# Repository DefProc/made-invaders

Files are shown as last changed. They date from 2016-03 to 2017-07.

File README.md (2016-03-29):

# made-invaders

A repo and issues list for the Made Invaders installation

The original test target display is the [ledframe](https://git.defproc.co.uk/DefProc/ledframe)

larger issues and discussins are in the [issues](https://github.com/DoESLiverpool/made-invaders/issues) but minute-by-minute planning is in the [trello board](https://trello.com/b/ncKjq608/made-invaders)

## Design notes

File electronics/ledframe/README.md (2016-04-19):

Known Issues
============

rev 1
-----

 * The 5V and ground on CON1 are reversed
   * **The D1, U1 and U3 WILL be damaged if the board is powered up**
   * Cutting the ground connections and the 5V line around the pads *must* be done
   before soldering. Then reversed connections will need to be added manually.
 * both SW1 and SW2 are rotated 90 degress from the correct connections.
   * Cutting diagonally opposed legs from the button before assembly will allow
   normal operation.
 * The ISCP slave select (SS) line is shared between IC1 and U2.
   * The ATmega *must* be programmed with a bootloader *before* soldering.
   * To program via ISCP, cut the RADIO_SS line between IC1 and U2.
 * The level converter (Q2, R3, R4) is too slow for the transmission speed required
 for the WS2812b LEDs.
   * Do not place Q1, R3 or R4. Make a bridge connection between pins 2–3 of Q2.

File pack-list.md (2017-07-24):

You will need:

 - [ ] Gazebo
 - [ ] 15 targets
 - [ ] Timer
 - [ ] Scoreboard
 - [ ] Blank boxes ×20
 - [ ] 2× 12v DC supply
 - [ ] Target power supply
 - [ ] Extra DC power cables
 - [ ] long kettle lead for the targets power
 - [ ] 2× Long 2way extensions
 - [ ] Play stand (and bucket o'darts)
 - [ ] the bowl of RFID tags
 - [ ] 15× Carpet tiles for flooring
 - [ ] Registration station Pi
 - [ ] RPi power supply
 - [ ] Keyboard
 - [ ] Monitor (hdmi)
 - [ ] Monitor power lead
 - [ ] HDMI cable
 - [ ] 4× Sidestrike nerf guns (the green ones)
 - [ ] 4× Jolt nerf guns (the small ones)
 - [ ] Battery nerf gun
 - [ ] 2× 12 shot clip
 - [ ] 1× 18 shot clip
 - [ ] Pull up banner
 - [ ] Hazard tape
 - [ ] Zip ties
 - [ ] 7× Safety glasses
 - [ ] M6x12 Bolts
 - [ ] M6x15 button cap bolts
 - [ ] M6 nuts

## If available

 - [ ] T-shirts
 - [ ] Stickers
 - [ ] Badges

## Maybe

 - [ ] Masking tape
 - [ ] Network cable
 - [ ] Network switch
 - [ ] Extensions
 - [ ] Power cable (for switch)
 - [ ] WiFi bridge laptop
 - [ ] Spare mouse

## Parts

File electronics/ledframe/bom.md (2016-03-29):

The BOM is on octopart at: [octopart.com/bom-lookup/logzmHi8](https://octopart.com/bom-lookup/logzmHi8).

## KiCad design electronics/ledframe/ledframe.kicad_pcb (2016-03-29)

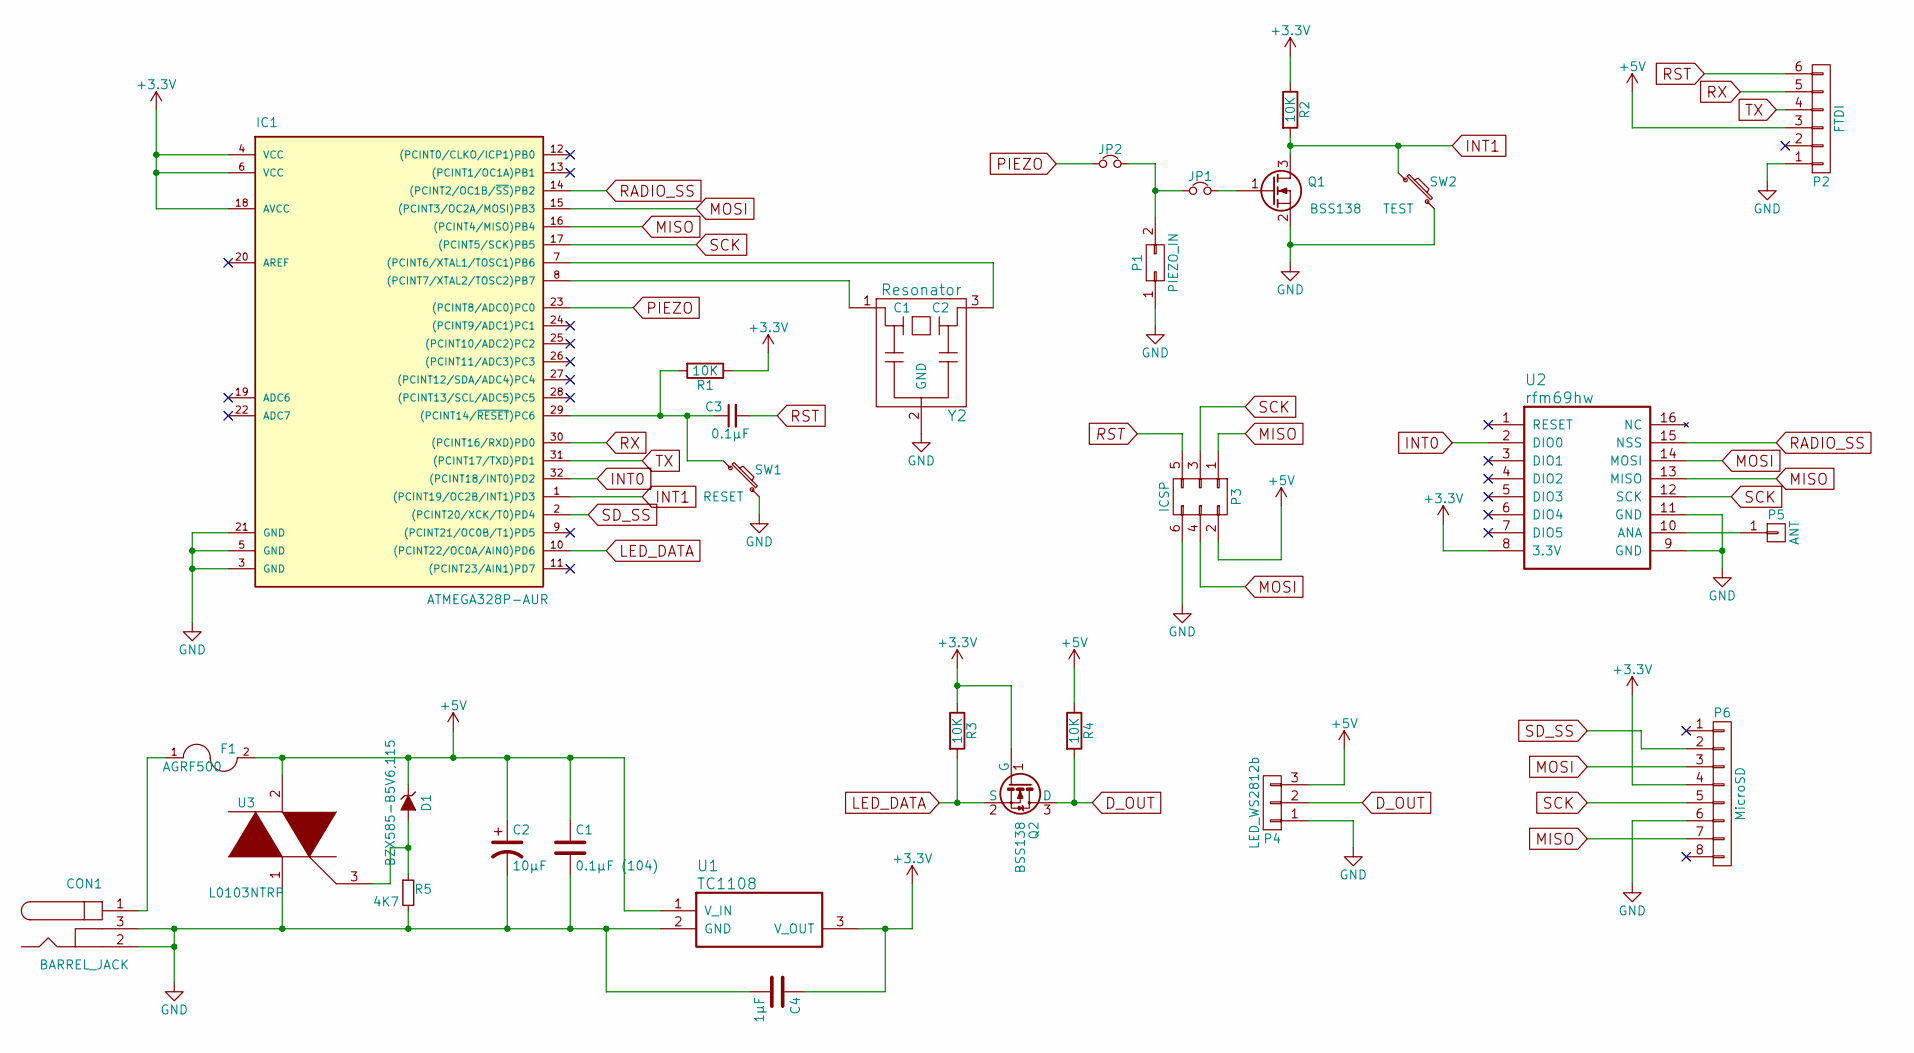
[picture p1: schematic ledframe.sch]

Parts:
C1: 0.1µF (104); C_0603
C2: 10µF; c_elec_3x5.3
C3: 0.1µF; C_0603
C4: 1µF; C_0805
CON1: BARREL_JACK
D1: BZX585-B5V6,115; SOD-523
F1: AGRF500; Resistor_Horizontal_RM7mm
IC1: ATMEGA328P-AUR; TQFP-32_7x7mm_Pitch0.8mm
JP1, JP2: Jumper_NC_Small; NC_SMD_JPR
P1: PIEZO_IN; Pin_Header_Straight_2x01
P2: FTDI; Pin_Header_Straight_1x06
P3: ICSP; Pin_Header_Straight_2x03
P4: LED_WS2812b; Pin_Header_Straight_1x03
P5: ANT; Socket_Strip_Straight_1x01
P6: MicroSD; MicroSD_Molex_47309
Q1, Q2: BSS138; SOT-23
R1, R2, R3, R4: 10K; R_0603
R5: 4K7; R_0603
SW1: RESET; KSEx00G_SW
SW2: TEST; KSEx00G_SW
U1: TC1108; SOT-223
U2: rfm69hw; DIP-16_W7.62mm
U3: L0103NTRP; SOT-223
Y2: Resonator; Resonator_3.2x1.3

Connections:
+3V3: C4.1, IC1.4 (VCC), IC1.6 (VCC), IC1.18 (AVCC), P6.4, Q2.1 (G), R1.1, R2.1, R3.1, U1.3 (V_OUT), U2.8 (3.3V)
+5V: C1.1, C2.1, D1.1 (K), F1.2, P2.3, P3.2, P4.3, R4.1, U1.1 (V_IN), U3.2
D_OUT: P4.2, Q2.3 (D), R4.2
GND: C1.2, C2.2, C4.2, CON1.2, CON1.3, IC1.3 (GND), IC1.5 (GND), IC1.21 (GND), P1.1, P2.1, P3.6, P4.1, P6.6, Q1.2 (S), R5.2, SW1.2, SW2.2, U1.2 (GND), U2.9 (GND), U2.11 (GND), U3.1, Y2.2 (GND)
INT0: IC1.32 ((PCINT18/INT0)PD2), U2.2 (DIO0)
INT1: IC1.1 ((PCINT19/OC2B/INT1)PD3), Q1.3 (D), R2.2, SW2.1
LED_DATA: IC1.10 ((PCINT22/OC0A/AIN0)PD6), Q2.2 (S), R3.2
MISO: IC1.16 ((PCINT4/MISO)PB4), P3.1, P6.7, U2.13 (MISO)
MOSI: IC1.15 ((PCINT3/OC2A/MOSI)PB3), P3.4, P6.3, U2.14 (MOSI)
unnamed: C3.1, IC1.29 ((PCINT14/~RESET~)PC6), R1.2, SW1.1
unnamed: CON1.1, F1.1
unnamed: D1.2 (A), R5.1, U3.3
unnamed: IC1.7 ((PCINT6/XTAL1/TOSC1)PB6), Y2.3 (C2)
unnamed: IC1.8 ((PCINT7/XTAL2/TOSC2)PB7), Y2.1 (C1)
unnamed: JP1.1, JP2.2, P1.2
unnamed: JP1.2, Q1.1 (G)
unnamed: P5.1, U2.10 (ANA)
PIEZO: IC1.23 ((PCINT8/ADC0)PC0), JP2.1
RADIO_SS: IC1.14 ((PCINT2/OC1B/~SS~)PB2), U2.15 (NSS)
RST: C3.2, P2.6, P3.5
RX: IC1.30 ((PCINT16/RXD)PD0), P2.5
SCK: IC1.17 ((PCINT5/SCK)PB5), P3.3, P6.5, U2.12 (SCK)
SD_SS: IC1.2 ((PCINT20/XCK/T0)PD4), P6.2
TX: IC1.31 ((PCINT17/TXD)PD1), P2.4

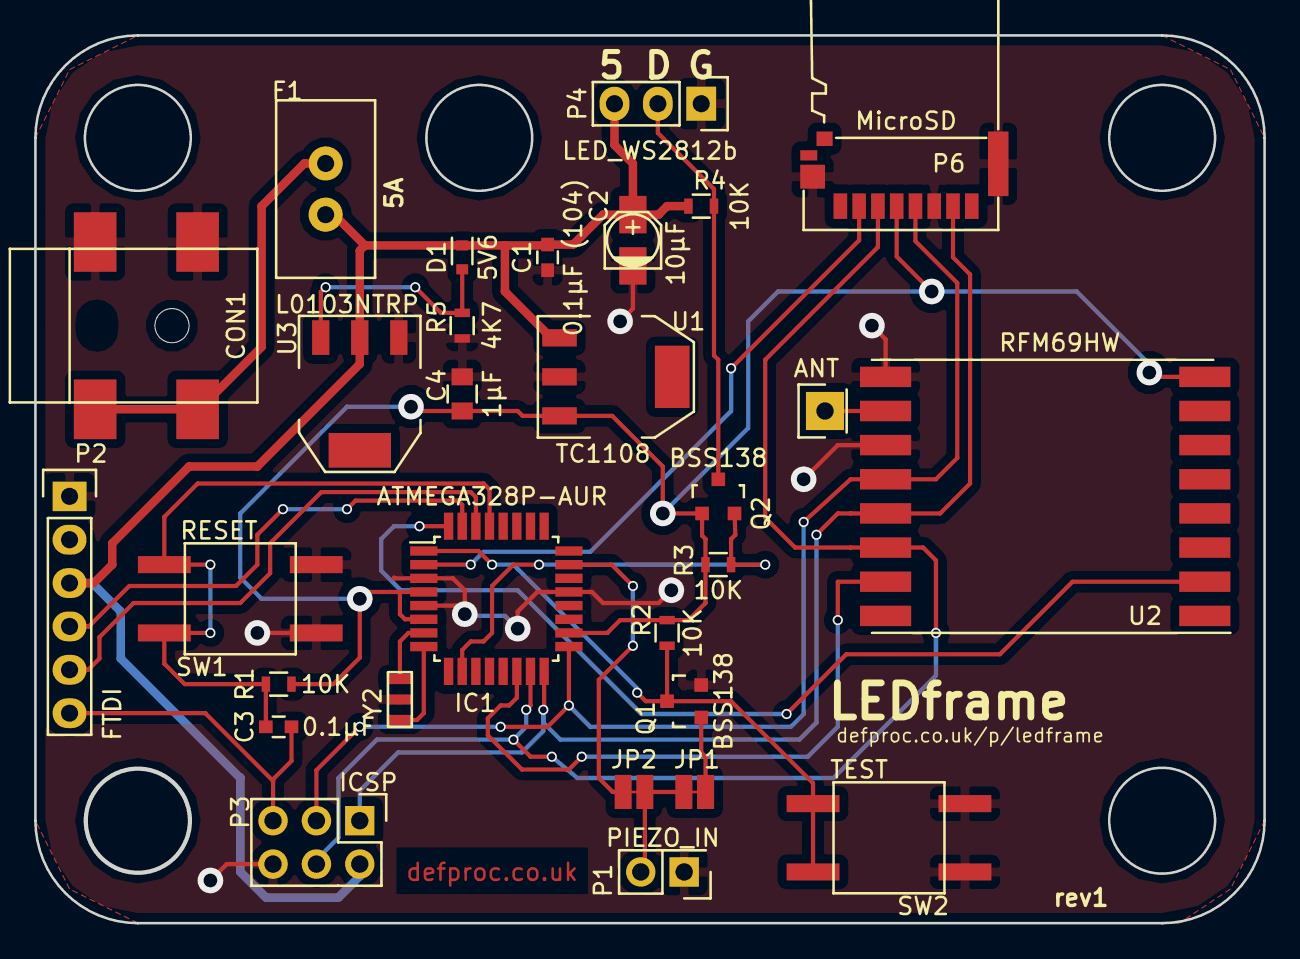
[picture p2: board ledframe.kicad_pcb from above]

Board: 2 copper layers, 72.0 x 52.0 mm, 29 parts (0 on the bottom side), 24 nets.

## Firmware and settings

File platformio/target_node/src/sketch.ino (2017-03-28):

#include "FastLED.h"
#include <SdFat.h>
#include <TimerOne.h>
#include <RFM69.h>
#include <SPI.h>
#include <Entropy.h>
#include <EEPROM.h>
#include "constants.h"
#include "secrets.h"
SdFat sd;
SdFile myFile;

// The unique identifier of this node
// targets are numbered 1-16,
uint8_t node_id;
RFM69 radio;

Payload myPacket;

// How many numbered images on the SD card?
uint8_t num_images;

#define BUTTON 3 // pin for the test button
#define BUTTON_TEST_DELAY 2000 // how long to press the button for test mode

#define BUFFPIXEL 20
#define NUM_LEDS 90
#define ARRAY_WIDTH 9
#define ARRAY_HEIGHT 9
#define DATA_PIN 6
// set the inital (default) frame hold time
#define FRAME_DELAY 250
// Define the array of leds
CRGB leds[NUM_LEDS];
// Error messages stored in flashread16(myFile).
#define error(msg) sd.errorHalt(F(msg))
// timer frequency for the ADC
const unsigned char PS_16 = (1 << ADPS2);
const unsigned char PS_128 = (1 << ADPS2) | (1 << ADPS1) | (1 << ADPS0);

// possible image states
enum image_state_t {
  STATIC,
  VERTICAL,
  HORIZONTAL
};

// System Setup
volatile boolean
  changeImage = true; // should we change the image to the next one?
boolean
  game_over = false,
  is_ready_to_play = false,
  show_help = false,
  test_images = false, // should we check the number of images on the SD (slow)
  singleGraphic = false, // single BMP file
  setupActive = false; // set brightness, playback mode, etc.
int
  currentButtonState = HIGH,
  lastButtonState = HIGH,
  offsetX = 0, // for translating images x pixels
  offsetY = 0; // for translating images y pixels
uint8_t
  analogThreshold = 70, // above what value should we take a reading as activated
  currentFrame = 0, // whick frame are we displaying
  numFrames = 1, // how many frames in the image animation?
  currentImage = -1; // which image are we looking at
uint16_t
  //currentScore = 0,
  imageWidth = 0,
  imageHeight = 0;
uint32_t
  gameStartTime = 0UL,
  frameDelay = FRAME_DELAY, // the time to hold each animation frame
  lastImageUpdate = 0UL, // when did we last change the displayed image
  impactRepeat = 100UL, // debounce timeout for the sensor
  idleAnimationSpacing = 1000;
volatile uint32_t
  lastButton = 0UL, // when did we last press the button
  lastImpact = 0UL; // when did we last see a hit
game_states_t play_state = RUNNING; // start the game running, allows demo from power on
image_state_t image_state = STATIC;
Payload theData; // incoming message buffer

int showImage(char* filename, uint32_t frame_delay = frameDelay, uint8_t first_frame = currentFrame, uint16_t num_frames = 0, uint16_t repeat_number = 1);

void setup() {
  Entropy.initialize();
  randomSeed(Entropy.random());

  Serial.begin(BAUD);
  Serial.println("starting target_node v1.1.0");

  // get the node id from EEPROM
  EEPROM.get(NODE_LOC, node_id);
  // check it's sensible, or reset to default
  if (node_id < NODE_MIN || node_id > NODE_MAX) {
    node_id = NODE_MIN;
    EEPROM.put(NODE_LOC, node_id);
  }
  Serial.print(F("I am target: "));
  Serial.println(node_id);

  // wait a small amount of time to prevent all the
  // targets from starting at once
  delay(100 * node_id);

  // set up the ADC sampling speed
  ADCSRA &= ~PS_128;  // remove bits set by Arduino library
  ADCSRA |= PS_16;    // set the prescaler to 16 (1MHz)

  // initialize the LED string
  FastLED.addLeds<WS2812,DATA_PIN,GRB>(leds,NUM_LEDS);
  FastLED.setBrightness(84);
  fill_solid(leds, NUM_LEDS, CRGB::Black);
  FastLED.show();

  // start the SD card
  if (!sd.begin(4, 6)) {
    // display an error pattern on SD fail
    showError(1);
    sd.initErrorHalt();
  } else {
    Serial.println(F("SD began"));
    //sd.ls(LS_R);
  }

  // get the number of images from EEPROM
  EEPROM.get(IMAGE_LOC, num_images);
  // check it's sensible, or reset to default
  if (num_images < IMAGE_DEFAULT || num_images > IMAGE_MAX) {
    num_images = IMAGE_DEFAULT;
    EEPROM.put(IMAGE_LOC, num_images);
  }
  Serial.print(F("Number of Images: "));
  Serial.println(num_images);

  // initialize the radio
  radio.initialize(FREQUENCY,node_id,NETWORKID);
  #ifdef IS_RFM69HW
  radio.setHighPower(); //uncomment only for RFM69HW!
  #endif
  radio.encrypt(ENCRYPTKEY);

  // show the colour wipe, so we know the display's working
  colour_wipe();

  // draw the invader logo
  clearStripBuffer();
  FastLED.show();
  delay(100);
  showImage("invader.bmp");
  delay(2000);
  clearStripBuffer();
  FastLED.show();

  // if we start RUNNING, start listening for hits
  if (play_state == RUNNING) { startScoring(); }
}

void showError(uint8_t error_code) {
  fill_solid(leds, NUM_LEDS, CRGB::Black);
  fill_solid(leds, error_code, CRGB::Red);
  FastLED.show();
}

void startScoring() {
  // Start the fast interrupt for the analog read
  pinMode(A0, INPUT);
  // TODO: include the analog input for more reliable scoring
  Timer1.initialize(10000); // run at 100Hz
  Timer1.attachInterrupt(checkImpact);

  // and start watching INT1 for too
  pinMode(3, INPUT);
  attachInterrupt(INT1, piezoInt, FALLING);

  gameStartTime = millis() - 1500UL;
  //currentScore = 0;
}

void stopScoring() {
  Timer1.detachInterrupt();
  detachInterrupt(INT1);
}

void fadeall() { for(int i = 0; i < NUM_LEDS; i++) { leds[i].nscale8(250); } }

void loop() {
  if (play_state == RFID_SCANNED) {
    // set the first image
    if (is_ready_to_play == false) {
      // pick a random image
      currentImage = random(0,num_images);
      char filename_buffer[13];
      sprintf(filename_buffer, "%04d.bmp", currentImage+1);
      if (sd.exists(filename_buffer)) {
        Serial.print(F("displaying "));
        Serial.println(filename_buffer);
        // show the first frame if it's an animation
        showImage(filename_buffer, 0, 0, 1);
        is_ready_to_play = true;
      } else {
        currentImage++;
        currentImage = currentImage % num_images;
      }
    } else if (image_state != STATIC && millis() - lastImageUpdate >= frameDelay) {
      // we should update the current image if it's an animation at it's time to
      char filename_buffer[13];
      sprintf(filename_buffer, "%04d.bmp", currentImage+1);
      // we've already checked that this exists
      showImage(filename_buffer, 0, currentFrame, 1);
    }
  } else if (play_state == RUNNING) {
    if (changeImage == true) {
      // change the image (ASAP)
      // TODO: this is where a better destroy animation should go
      destroy();
      // Then report the hit via the RFM69
      myPacket.message_id = HIT;
      myPacket.impact_num++;
      myPacket.timestamp = millis() - gameStartTime;
      if (radio.sendWithRetry(MAIN_CTRL, (const void*)(&myPacket), sizeof(myPacket), 5)) {
        Serial.println(F("sent impact message"));
      } else {
        Serial.println(F("no radio message sent"));
        showError(3);
      }
      //Then show the next character
      // TODO: we should at least check that we don't get the same number again
      currentImage = random(0,num_images);
      char filename_buffer[13];
      sprintf(filename_buffer, "%04d.bmp", currentImage+1);
      if (sd.exists(filename_buffer)) {
        Serial.print(F("displaying "));
        Serial.println(filename_buffer);
        showImage(filename_buffer, 0, 0, 1);
        changeImage = false;
      }
    } else if (image_state != STATIC && millis() - lastImageUpdate >= frameDelay) {
      // we should update the current image if it's an animation at it's time to
      char filename_buffer[13];
      sprintf(filename_buffer, "%04d.bmp", currentImage+1);
      // we've already checked that this exists
      showImage(filename_buffer, 0, currentFrame, 1);
    }
  } else if (play_state == END_GAME) {
    if (game_over == true) {
      // show a red screen for the finish
      fill_solid(leds, NUM_LEDS, CRGB::Red);
      for (uint8_t i; i<10; i++) {
        FastLED.show();
        delay(100);
        for (int j; j<NUM_LEDS; j++) {
          leds[j].fadeToBlackBy(64);
        }
      }
      fill_solid(leds, NUM_LEDS, CRGB::Black);
      FastLED.show();
      game_over = false;
    }
  } else if (play_state == IDLE) {
    bool go_to_test_mode = false;

    // if there's any serial available, read it:
    while (Serial.available() > 0) {
      char character = Serial.read();
      if (character == 't' || character == 'T') {
        test_images = false;
        show_help = true;
        go_to_test_mode = true;
      } else if (character == 's' || character == 'S') {
        play_state = RUNNING;
        startScoring();
      }
    }

    // check if we should be changing to TEST mode
    currentButtonState = digitalRead(BUTTON);
    if (digitalRead(BUTTON) == LOW) {
      // button is pressed
      if (currentButtonState != lastButtonState) {
        // it's just been pressed
        lastButton = millis();
        lastButtonState = currentButtonState;
        Serial.print(F("button pressed, counting"));
      } else {
        if (millis() - lastButton >= BUTTON_TEST_DELAY) {
          // enter test mode
          Serial.println(F("held long enough"));
          test_images = true;
          show_help = false;
          go_to_test_mode = true;
        }
      }
    } else {
      // button is released
      lastButtonState = currentButtonState;
    }

    if (go_to_test_mode == true) {
        Serial.println(F("Testing mode (reset to exit)"));
        Serial.println(F("n<number> to set node_id (1-16)"));
        Serial.println(F("i to recount the number of images"));
        show_help = true;
        play_state = TEST;
    }

    // just show a scrolling
    if (millis() - lastImageUpdate >= idleAnimationSpacing) {
      // TODO: it sometimes freezes on the animation
      //showImage("title.bmp", 30);
      // lets try a pulse instead
      uint8_t fade_colour = random(5);
      switch (random(5)) {
        case 1:
          fill_solid(leds, NUM_LEDS, CRGB::Magenta);
          break;
        case 2:
          fill_solid(leds, NUM_LEDS, CRGB::Red);
          break;
        case 3:
          fill_solid(leds, NUM_LEDS, CRGB::Yellow);
          break;
        case 4:
          fill_solid(leds, NUM_LEDS, CRGB::Green);
          break;
        default:
          fill_solid(leds, NUM_LEDS, CRGB::White);
          break;
      }
      FastLED.show();
      for (int i=0; i<10; i++) {
        leds[i].fadeToBlackBy(64);
        FastLED.show();
        delay(10);
      }
      fill_solid(leds, NUM_LEDS, CRGB::Black);
      FastLED.show();
      lastImageUpdate = millis();
      idleAnimationSpacing = random(2500, 30000);
    } else {
      fill_solid(leds, NUM_LEDS, CRGB::Black);
      FastLED.show();
    }
  } else if (play_state == TEST) {
    while (Serial.available() > 0) {
      char character = Serial.read();

      if (character == 'h' || character == 'H') {
        // show the menu
        show_help = true;
      }

      if (character == 'n' || character == 'N') {
        // set node id
        uint8_t new_node_id = Serial.parseInt();
        EEPROM.update(NODE_LOC, new_node_id);
        Serial.print(F("Node ID set to: "));
        Serial.println(new_node_id);
        Serial.println(F("reset to use"));
      }

      if (character == 'i' || character == 'I') {
        // count the images on the SD card
        test_images = true;
      }

      if (character == 'x' || character == 'q' || character == 'X' || character == 'Q') {
        play_state = IDLE;
        Serial.println(F("go to IDLE mode"));
      }
    }

    if (test_images == true) {
      // check the number of images on the SD card
      Serial.println(F("checking the number of images on the card"));
      Serial.println(F("we may be some time"));
      fill_solid(leds, NUM_LEDS, CRGB::Green);
      FastLED.show();
      delay(100);
      fill_solid(leds, NUM_LEDS, CRGB::Black);
      FastLED.show();
      uint8_t num_images = 0;
      for (int i = 0; i<=IMAGE_MAX; i++) {
        char filename_buffer[13];
        sprintf(filename_buffer, "%04d.bmp", i+1);
        //myFile.close();
        Serial.print(filename_buffer);
        if (sd.exists(filename_buffer)) {
          showImage(filename_buffer, 0, 0, 1);
          delay(250);
          for (int j=0; j<i; j++) {
            leds[j] = CRGB::Yellow;
          }
          FastLED.show();
          Serial.println(F(" exists"));
          num_images++;
          delay(100);
        } else {
          Serial.println(F(" not found"));
          break;
        }
      }
      Serial.print(num_images);
      Serial.println(F(" images found"));
      test_images = false;
      //write this value to the EEPROM for next time
      EEPROM.update(IMAGE_LOC, num_images);
      delay(500);
      fill_solid(leds, NUM_LEDS, CRGB::Black);
      FastLED.show();
    }

    if (show_help == true) {
      // show the possible options
      Serial.println(F("Testing mode (reset to exit)"));
      Serial.println(F("n<number> to set node_id (1-16)"));
      Serial.println(F("i to recount the number of images"));
      Serial.println(F("x|q to quit to IDLE mode"));
      show_help = false;
    }
  } // end of state machine

  // let's check any incoming messages
  checkIncoming();
}

void colour_wipe() {
  static uint8_t hue = 0;
  Serial.print("x");
  // First slide the led in one direction
  for(int i = 0; i < NUM_LEDS; i++) {
    // Set the i'th led to red
    leds[i] = CHSV(hue++, 255, 255);
    // Show the leds
    FastLED.show();
    //now that we've shown the leds, reset the i'th led to black
    // leds[i] = CRGB::Black;
    fadeall();
    // Wait a little bit before we loop around and do it again
    delay(10);
  }
  Serial.print("x");

  // Now go in the other direction.
  for(int i = (NUM_LEDS)-1; i >= 0; i--) {
    // Set the i'th led to red
    leds[i] = CHSV(hue++, 255, 255);
    // Show the leds
    FastLED.show();
    // now that we've shown the leds, reset the i'th led to black
    // leds[i] = CRGB::Black;
    fadeall();
    // Wait a little bit before we loop around and do it again
    delay(10);
  }
}

void checkImpact() {
  if (analogRead(A0) >= analogThreshold && millis() - lastImpact >= impactRepeat) {
    changeImage = true;
    lastImpact = millis();
    //currentScore++;
  }
}

void piezoInt() {
  if (millis() - lastImpact >= impactRepeat) {
    changeImage = true;
    lastImpact = millis();
    //currentScore++;
    //Serial.println(F("interrupt"));
  }
}

void destroy() {
  fill_solid(leds, NUM_LEDS, CRGB::Black);
  FastLED.show();
  delay(50);
  //fill_solid(leds, NUM_LEDS, CRGB::Red);
  for (uint8_t i=0; i<NUM_LEDS; i++) {
    if (random(10) < 7) { leds[i] = CRGB::Red; }
  }
  FastLED.show();
  delay(50);
  fill_solid(leds, NUM_LEDS, CRGB::Black);
  FastLED.show();
  delay(50);
  //fill_solid(leds, NUM_LEDS, CRGB::Orange);
  for (uint8_t i=0; i<NUM_LEDS; i++) {
    if (random(10) < 4) { leds[i] = CRGB::White; }
  }
  FastLED.show();
  delay(50);
  fill_solid(leds, NUM_LEDS, CRGB::Black);
  FastLED.show();
  delay(50);
  //fill_solid(leds, NUM_LEDS, CRGB::Yellow);
  for (uint8_t i=0; i<NUM_LEDS; i++) {
    if (random(10) < 1) { leds[i] = CRGB::Yellow; }
  }
  FastLED.show();
  delay(50);
  fill_solid(leds, NUM_LEDS, CRGB::Black);
  FastLED.show();
  delay(100);
}

// This function opens a Windows Bitmap (BMP) file and
// displays it at the given coordinates.  It's sped up
// by reading many pixels worth of data at a time
// (rather than pixel by pixel).  Increasing the buffer
// size takes more of the Arduino's precious RAM but
// makes loading a little faster.  20 pixels seems a
// good balance.

void bmpDraw(char *filename, uint8_t x, uint8_t y) {

  int  bmpWidth, bmpHeight;   // W+H in pixels
  uint8_t  bmpDepth;              // Bit depth (currently must be 24)
  uint32_t bmpImageoffset;        // Start of image data in file
  uint32_t  rowSize;               // Not always = bmpWidth; may have padding
  uint8_t  sdbuffer[3*BUFFPIXEL]; // pixel buffer (R+G+B per pixel)
  uint8_t  buffidx = sizeof(sdbuffer); // Current position in sdbuffer
  boolean  goodBmp = false;       // Set to true on valid header parse
  boolean  flip    = true;        // BMP is stored bottom-to-top
  int  w, h, row, col;
  uint8_t  r, g, b;
  uint32_t pos = 0;
  const uint8_t  gridWidth = ARRAY_WIDTH;
  const uint8_t  gridHeight = ARRAY_HEIGHT;

  //if((x >= gridWidth) || (y >= gridHeight)) {
    //Serial.print(F("Abort."));
    //return;
  //}

  Serial.println();

  if (!myFile.isOpen())
  {
    //Serial.print(F("Loading image '"));
    //Serial.print(filename);
    //Serial.println('\'');
    // Open requested file on SD card
    myFile.close();
    if (!myFile.open(filename, O_READ)) {
      Serial.print(F("File open failed "));
      Serial.println(filename);
      //sdErrorMessage();
      //try reinitialise:
      showError(1);
      sd.begin(4,6);
      return;
    }
  }
  else myFile.rewind();

  // Parse BMP header
  uint16_t bmp_sig = read16(myFile);
  //if(read16(myFile) == 0x4D42) { // BMP signature
  if(bmp_sig == 0x4D42) { // BMP signature
    Serial.print(F("File size: ")); Serial.println(read32(myFile));
    (void)read32(myFile); // Read & ignore creator bytes
    bmpImageoffset = read32(myFile); // Start of image data
    Serial.print(F("Image Offset: ")); Serial.println(bmpImageoffset, DEC);
    // Read DIB header
    Serial.print(F("Header size: ")); Serial.println(read32(myFile));
    bmpWidth  = read32(myFile);
    bmpHeight = read32(myFile);
    if(read16(myFile) == 1) { // # planes -- must be '1'
      bmpDepth = read16(myFile); // bits per pixel
      //Serial.print(F("Bit Depth: ")); Serial.println(bmpDepth);
      if((bmpDepth == 24) && (read32(myFile) == 0)) { // 0 = uncompressed

        goodBmp = true; // Supported BMP format -- proceed!
        //Serial.print(F("Image size: "));
        //Serial.print(bmpWidth);
        //Serial.print('x');
        //Serial.println(bmpHeight);

        //Serial.print(F("Image offset: "));
        //Serial.print(offsetX);
        //Serial.print(F(", "));
        //Serial.println(offsetY);

        // image smaller than 16x16?
        if ((bmpWidth < ARRAY_WIDTH && bmpWidth > -ARRAY_WIDTH) || (bmpHeight < ARRAY_HEIGHT && bmpHeight > -ARRAY_HEIGHT))
        {
          clearStripBuffer();
        }

        // BMP rows are padded (if needed) to 4-byte boundary
        rowSize = (bmpWidth * 3 + 3) & ~3;;
        //Serial.print(F("Row size: "));
        //Serial.println(rowSize);


        // If bmpHeight is negative, image is in top-down order.
        // This is not canon but has been observed in the wild.
        if(bmpHeight < 0) {
          bmpHeight = -bmpHeight;
          flip      = false;
        }

        // Crop area to be loaded
        w = bmpWidth;
        h = bmpHeight;
        if((x+w-1) >= gridWidth)  w = gridWidth - x;
        if((y+h-1) >= gridHeight) h = gridHeight - y;

        for (row=0; row<h; row++) { // For each scanline...

          // Seek to start of scan line.  It might seem labor-
          // intensive to be doing this on every line, but this
          // method covers a lot of gritty details like cropping
          // and scanline padding.  Also, the seek only takes
          // place if the file position actually needs to change
          // (avoids a lot of cluster math in SD library).

          if(flip) // Bitmap is stored bottom-to-top order (normal BMP)
            pos = (bmpImageoffset + (offsetX * -3) + (bmpHeight - 1 - (row + offsetY)) * rowSize);
          else     // Bitmap is stored top-to-bottom
            pos = bmpImageoffset + row * rowSize;
          if(myFile.curPosition() != pos) { // Need seek?
            myFile.seekSet(pos);
            buffidx = sizeof(sdbuffer); // Force buffer reload
          }

          for (col=0; col<w; col++) { // For each pixel...
            // Time to read more pixel data?
            if (buffidx >= sizeof(sdbuffer)) { // Indeed
              myFile.read(sdbuffer, sizeof(sdbuffer));
              buffidx = 0; // Set index to beginning
            }

            // push to LED buffer
            b = sdbuffer[buffidx++];
            g = sdbuffer[buffidx++];
            r = sdbuffer[buffidx++];

            // offsetY is beyond bmpHeight
            if (row >= bmpHeight - offsetY)
            {
              // black pixel
              leds[getIndex(col, row)] = CRGB::Black;
              //led[getIndex(col, row)] strip.Color(0, 0, 0));
            }
            // offsetY is negative
            else if (row < offsetY * -1)
            {
              // black pixel
              leds[getIndex(col, row)] = CRGB::Black;
              //strip.setPixelColor(getIndex(col, row), strip.Color(0, 0, 0));
            }
            // offserX is beyond bmpWidth
            else if (col >= bmpWidth + offsetX)
            {
              // black pixel
              leds[getIndex(col, row)] = CRGB::Black;
              //strip.setPixelColor(getIndex(col, row), strip.Color(0, 0, 0));
            }
            // offsetX is positive
            else if (col < offsetX)
            {
              // black pixel
              leds[getIndex(col, row)] = CRGB::Black;
              //strip.setPixelColor(getIndex(col, row), strip.Color(0, 0, 0));
            }
            // all good
            else {
              leds[getIndex(col+x, row)].setRGB(r, g, b);
              //strip.setPixelColor(getIndex(col+x, row), strip.Color(r, g, b));
            }
            // paint pixel color
          } // end pixel
        } // end scanline
      } // end goodBmp
    }
  }
  FastLED.show();

  if (singleGraphic == false || setupActive == true)
  {
    //Serial.println(F("Closing Image..."));
    myFile.close();
  }
  if(!goodBmp) {
    Serial.print(F("Format unrecognized: "));
    Serial.println(bmp_sig);
    showError(8);
  }
}
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

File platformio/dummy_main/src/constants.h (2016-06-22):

// some basic constants for everybody
#define BAUD 115200 // serial baud rate is then contsant accross all devices
#define RFID_DIGITS 16 // max number of chars to hold an scanned ID
#define NUM_TARGETS 16 // how many targets do we have

// target node EEPROM locations
#define NODE_LOC 1
#define NODE_MIN 1
#define NODE_MAX 16
#define IMAGE_LOC 5
#define IMAGE_DEFAULT 5
#define IMAGE_MAX 200

// some unsigned long values for the various timer lengths
#define RUN_TIMER 30000UL // play time in ms
#define GRACE_TIMER 250UL // this is a bit of a fude so it *looks* like the game ends at zero
#define EARLY_PLAY 1000UL
#define EXTRA_TIMER 30000UL // how much extra time for a zero score
#define IDLE_TIMER 60000UL // wait a minute before going into attract mode
#define COUNT_DOWN 5000UL

// RFM69 constants
#define NETWORKID     101  // The same on all nodes that talk to each other
#define MAIN_CTRL     200  // The Main Controller
#define REG_STN       201  // Registration station interpretter (to RPi)
#define TIMER         202  // Countdown Timer
#define SCOREBD       203  // The Score Board
#define FREQUENCY     RF69_868MHZ
#define IS_RFM69HW

// set the possible messages (in message_id)
enum message_t : uint8_t {
  GAME_START,
  TAKE_PHOTO,
  GAME_END,
  NOTHING_DOING,
  CANCEL_GAME,
  GET_READY,
  HIT,
  DISPLAY_NUM,
  MORE_TIME,
  FALSE_START,
  RUN_COUNTDOWN,
};

typedef struct {
  message_t message_id = GAME_START;
  uint32_t impact_num = 0UL;
  long timestamp = 0L;
  char rfid_num[RFID_DIGITS+1];
  uint32_t game_uid;
  long score = 0L;
} Payload;

enum game_states_t {
  IDLE,
  RFID_SCANNED,
  COUNTDOWN,
  RUNNING,
  EXTRA_TIME,
  END_GAME,
  TEST
};

// to allow builtin LED use on Moteino/Moteino Mega
#ifdef __AVR_ATmega1284P__
  #define LED           15 // Moteino MEGAs have LEDs on D15
  #define FLASH_SS      23 // and FLASH SS on D23
#else
  #define LED           9 // Moteinos have LEDs on D9
  #define FLASH_SS      8 // and FLASH SS on D8
#endif

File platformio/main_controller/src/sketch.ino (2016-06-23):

#include <SD.h>
#include <RFM69.h>
#include <SPI.h>
#include <SPIFlash.h>
#include <avr/wdt.h>
#include <WirelessHEX69.h>
#include <Wire.h>
#include <SL018.h>
#include <RTClib.h>
#include <SOMO_II.h>
#include "constants.h"
#include "secrets.h"

SL018 rfid;
RFM69 radio;
SPIFlash flash(FLASH_SS, 0xEF30); //EF30 for windbond 4mbit flash

// set the appropiate node ID
#define NODEID MAIN_CTRL    // The Gateway runs on node 200

// set up the somo-ii connection
SOMO_II mp3 = SOMO_II(Serial1);

// button and led connections
#define START_BUTTON  13
#define CANCEL_BUTTON 12
#define START_LED     15

// Lets get the global variables some space
Payload theData; // somewhere to store incoming data
Payload myPacket; // and one for oddutgoing
game_states_t game_state = IDLE;
char player_rfid[RFID_DIGITS+1];
long
  remaining_game_time = 0,
  current_score = 0;
unsigned long
  number_of_hits = 0,
  start_time = 0,
  game_uid = 0;
volatile bool
  update_scoreboard = false,
  take_photo = false;

// set the target scores:
long scoremap[] = { 101, 236, 553, 100, 1234, 5120, -100, 999, 1024, 512, 256, 128, 200, 865, 6547, 450 };
unsigned long hit_record[sizeof(scoremap)];

void setup() {
  // idiot pause on startup
  delay(2000);

  Wire.begin();
  Serial.begin(BAUD);
  Serial.println("starting made-invaders main_controller…");

  // initialise the music player
  Serial1.begin(SOMO_BAUD);
  mp3.begin();
  Serial.println(F("MP3 OK"));
  delay (1000);

  mp3.playFile(1, 6); //new start file
  Serial.println(F("Playing START.MP3"));

  // initialize the radio
  radio.initialize(FREQUENCY,NODEID,NETWORKID);
#ifdef IS_RFM69HW
  radio.setHighPower();
#endif
  radio.encrypt(ENCRYPTKEY);

  // set up the button an led pins
  pinMode(START_LED, OUTPUT);
  pinMode(START_BUTTON, INPUT);
  pinMode(CANCEL_BUTTON, INPUT);

  // lets just prep the rfid array with zeros
  for (int i=0; i<RFID_DIGITS; i++) {
    myPacket.rfid_num[i] = '0';
  }

  Blink(START_LED, 1000);
  Serial.println(F("end of setup"));
}

uint16_t ackCount = 0;
void loop() {
  // start the state machine
  if (game_state == IDLE) {

    Serial.println(F("IDLE state"));
    start_time = millis();
    bool nothing_doing = false; // have we sent a "nothing doing" message
    // hold for rfid read
    Serial.println(F("waiting for rfid tag"));
    // we're waiting for an RFID scan
    rfid.seekTag();
    unsigned long play_repeat = 360000;
    unsigned long last_played_at = millis() - play_repeat + IDLE_TIMER;
    while (!rfid.available()) {
      if (nothing_doing == false) {
        if (millis() - start_time >= IDLE_TIMER) {
          Serial.println(F("nothing doing"));
          // broadcast NOTHING_DOING to go to idle mode
          myPacket.game_uid = 0;
          myPacket.impact_num = 0;
          myPacket.score = 0;
          for (int i=0; i<RFID_DIGITS; i++) {
            myPacket.rfid_num[i] = '0';
          }
          myPacket.timestamp = 0;
          myPacket.message_id = NOTHING_DOING;
          broadcastMessage(NOTHING_DOING);
          nothing_doing = true;
        }
      } else {
        if (millis() - last_played_at >= play_repeat) {
          // Play the idle theme
          Serial.println(F("Playing Ed's music that sounds like donkey kong country"));
          mp3.playFile(1,9);
          last_played_at = millis();
        }
      }
    }
    strncpy(player_rfid, rfid.getTagString(), sizeof(player_rfid));
    // then change this to lower case because Brett insisted
    for (int i=0; i<sizeof(player_rfid); i++) {
      player_rfid[i] = tolower(player_rfid[i]);
    }
    // and print to serial so we can see too
    Serial.print(F("rfid: "));
    Serial.println(player_rfid);
    // copy all the game variables into the right places for sending
    strncpy(myPacket.rfid_num, player_rfid, sizeof(myPacket.rfid_num));
    myPacket.game_uid = game_uid;
    myPacket.impact_num = 0;
    myPacket.score = 0;
    myPacket.timestamp = 30000;
    // let everybody know what's happening
    broadcastMessage(GET_READY);
    // lets at least try to make sure the registration station gets this
    //radio.sendWithRetry(REG_STN, (const void*)&myPacket, sizeof(myPacket), 5);
    game_state = RFID_SCANNED;
  } else if (game_state == RFID_SCANNED) {
    Serial.println(F("RFID_SCANNED"));
    mp3.playFile(1,7);
    //pulse the led to show we're waiting for input
    int start_button_state = LOW;
    int cancel_button_state = LOW;
    while(start_button_state == LOW && cancel_button_state == LOW) {
      float val = (exp(sin(millis()/1000.0*PI)) - 0.36787944)*108.0;
      analogWrite(START_LED, val);
      start_button_state = digitalRead(START_BUTTON);
      cancel_button_state = digitalRead(CANCEL_BUTTON);
    }
    delay(100);
    digitalWrite(START_LED, LOW);
    if (start_button_state == HIGH) {
      game_state = COUNTDOWN;
    } else {
      broadcastMessage(CANCEL_GAME);
      game_state = IDLE;
    }
  } else if (game_state == COUNTDOWN) {
    Serial.println(F("COUNTDOWN"));
    // run through the countdown activities
    // this state is pretty time critical

    // reset all the game counters
    current_score = 0;
    number_of_hits = 0;
    for (int i=0; i<sizeof(scoremap); i++) {
       hit_record[i] = 0;
    }
    update_scoreboard = true; // make sure we get an inital refresh to zero
    take_photo = true;

    // then make the countdown
    myPacket.message_id = RUN_COUNTDOWN;
    myPacket.score = 5;
    radio.sendWithRetry(SCOREBD, (const void*)&myPacket, sizeof(myPacket), 5);
    //delay(50);
    Serial.print(F("5… "));
    mp3.playFile(1,5);
    long countdown_timer = millis();
    while (millis() - countdown_timer <= 1000UL);
    mp3.stop();
    mp3.playFile(1,4);
    Serial.print(F("4… "));
    while (millis() - countdown_timer <= 2000UL);
    mp3.stop();
    delay(10);
    mp3.playFile(1,3);
    Serial.print(F("3… "));
    while (millis() - countdown_timer <= 3000UL);
    mp3.stop();
    delay(10);
    mp3.playFile(1,2);
    Serial.print(F("2… "));
    myPacket.message_id = GAME_START;
    myPacket.timestamp = -1500L;
    // broadcast game start
    radio.send(0xFF, (const void*)&myPacket, sizeof(myPacket));
    while (millis() - countdown_timer <= 4000UL) {
      checkTargets();
    }
    Serial.print(F("1… "));
    mp3.stop();
    delay(10);
    mp3.playFile(1,2);
    while(millis() - countdown_timer <= 5000UL);
    game_state = RUNNING;
    Serial.println(F("RUNNING"));
    mp3.stop();
    delay(10);
    mp3.playFile(1,6);
    // send a directed start message to begin the timer
    start_time = millis();
    myPacket.message_id = GAME_START;
    //radio.sendWithRetry(TIMER, (const void*)&myPacket, sizeof(myPacket), 3);
    radio.send(TIMER, (const void*)&myPacket, sizeof(myPacket));
    while (millis() - countdown_timer <= 6000UL);
    mp3.stop();
    delay(10);
    mp3.playFile(1,random(10, 13));
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

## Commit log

2016-03-02 include ledframe link
2016-03-02 draft of target circuit
    [ledframe.kicad_pcb, ledframe.sch, rfm69hw.csv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]
2016-03-14 EOD: there's a circuit, but no board layout yet
    [ledframe.kicad_pcb, ledframe.sch]
2016-03-18 included the inital test images for the ledframe
2016-03-27 changed to resonator
    [ledframe.sch]
2016-03-27 draft layout. still needs rfm69 and resonator footprints
    [ledframe.kicad_pcb]
2016-03-27 first draft routing
    [ledframe.kicad_pcb]
2016-03-27 included the missing resonator(!)
    [ledframe.kicad_pcb, ledframe.sch]
2016-03-28 issues and trello board links
2016-03-29 generated gerbers
    [ledframe-B.Cu.gbr, ledframe-B.Mask.gbr, ledframe-B.Paste.gbr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]
2016-03-29 removed an alignment target from the board
    [ledframe-B.Cu.gbr, ledframe-B.Mask.gbr, ledframe-B.Paste.gbr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]
2016-03-29 included a link to the bom
2016-04-03 removed the text and elastics holes; added a space for the piezo to go through
2016-04-07 brought across the MFUKLC arduino code
2016-04-07 included a slot for the piezo to go through
2016-04-07 new string test for checking LEDs before making the arrays
2016-04-11 fixed the nerf_test, and included TimerOne library too
    [sketch.ino]
2016-04-13 main play stand cut files
2016-04-13 and a cut file for the rfid area cover
2016-04-14 cut files for the power supply cover
2016-04-14 change to sdcard invader logo, and have 9×9 array in 90 led string
2016-04-14 added the known issues with the rev1 ledframe boards
2016-04-16 included the vinyl cut files for the box pixel patterns
2016-04-16 included the interrupt pin on the sensor too
2016-04-19 include the SPIflash and WirelessProgramming libraries
2016-04-19 included wireless programming option for the test_receiver
2016-04-19 reversed the radio send order till after the image change
    [sketch.ino]
2016-04-19 and the typos fixed…
    [sketch.ino]
2016-04-20 draft of the RFM69 activated timer (and scoreboard) code
2016-04-20 some adjustments to the main controller for debugging and play flow
2016-04-20 corrected the registration station, and added the get ready message
    [sketch.ino]
2016-04-20 and sorted the rfid reader (n.b. must call Wire.begin() for I2C!
2016-04-20 more robust start/cancel button, broadcast start game later
2016-04-20 corrected the timer, set the main controller timer flow and added more images to the target
    [sketch.ino]
2016-04-20 and the timers must be unsigned longs!!
2016-04-21 included options for timer OR scoreboard
2016-04-21 updated pin defs, so mp3 player DREQ is on INT0
2016-04-21 Fixed file names typos and changed mp3 file permissions
    [sketch.ino]
2016-04-22 OTD: sd.begin on failed image, reduced serial on bmpDraw()
    [sketch.ino]
2016-04-23 added target error reporting on the leds, and red flash on END_GAME
    [sketch.ino]
2016-06-23 bug fixes and smooth running on the main and targets
    [sketch.ino]
2016-10-27 corrected auto start and added the countdown timer radio calls
    [sketch.ino]
